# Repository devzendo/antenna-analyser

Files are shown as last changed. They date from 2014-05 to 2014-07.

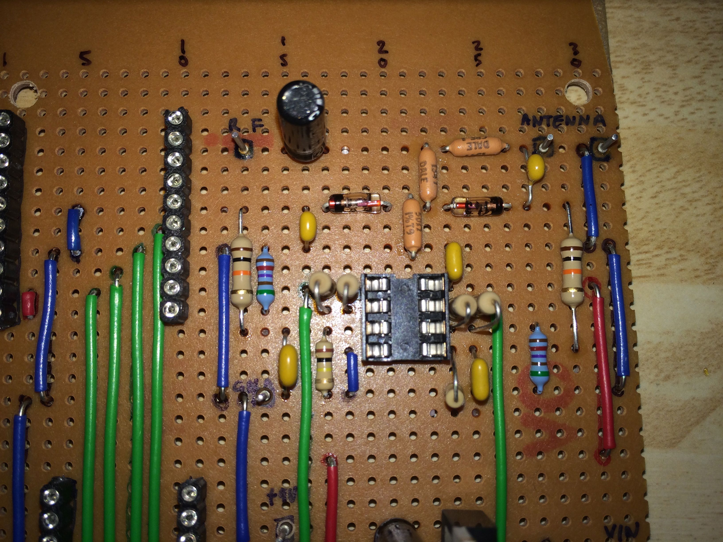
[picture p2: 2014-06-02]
IMG_2970.jpg

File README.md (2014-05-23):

antenna-analyser
================

Code, documents and details of one way to construct Beric Dunn K6BEZ' inexpensive antenna analyser.

Details of Beric's project's several variations, and schematics can be found at http://www.hamstack.com/project_antenna_analyzer.html

This repository, and the blog posts at http://mattgumbley.wordpress.com/category/amateur-radio/antenna-analyser/ hold
details of my construction attempts, board layouts, component costs, software, tests, and articles on VSWR (my
attempts to learn more about it by writing about it) and RF circuit design.

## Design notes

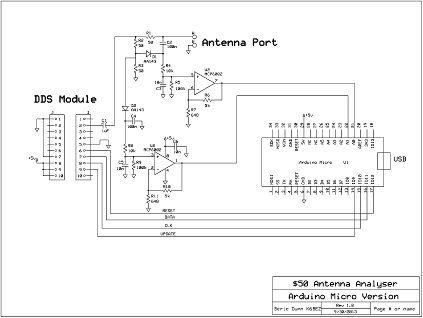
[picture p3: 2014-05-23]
BericSchematicSmall.png

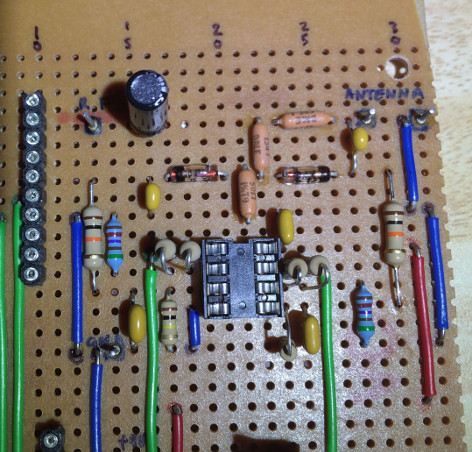
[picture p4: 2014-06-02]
PhotoBridgeDetail.jpg

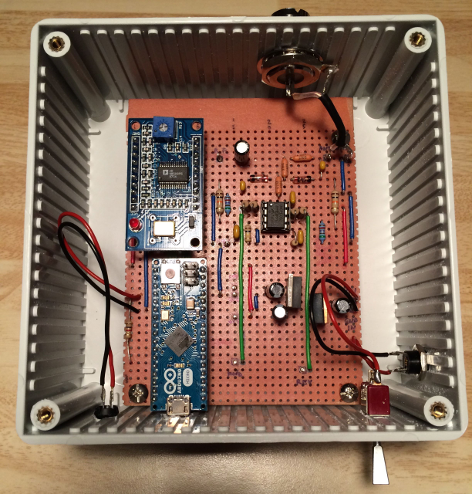
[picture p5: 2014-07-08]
PhotoEnclosureOpen.png

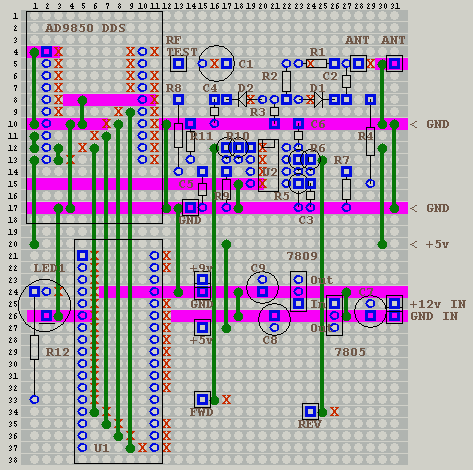
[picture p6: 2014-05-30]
GroundContinuity.png

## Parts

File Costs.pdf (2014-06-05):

## Sheet1

## Page 1

| | | Farnell | RS | Chosen
Component | Value | Num | Code | Cost | Code | Cost | Cost | Total Note
U1 | Arduino Micro | 1 | | | 771-7667 | £15.74 | £15.74 | £15.74 With headers
DDS | DDS Module | 1 | | | | | £7.99 | £7.99 | AD9850 DDS Signal 0-40MHz from 'heavends' on eBay (UK merchant)
U2 | MCP6002 | 1 | | | 403-036 | £0.24 | £0.24 | £0.24 MCP6002-I/P Dual Op-Amp 1MHz CMOS R-R 3, 5V 8-Pin PDIP
U3 | LM7805CT | 1 | | | 671-0309 | £0.49 | £0.49 | £0.49
U4 | L7809CV | 1 | 1087089 | £0.42 | | | £0.42 | £0.42
D1,2 | AA143 | 2 | | | | | £0.60 | £1.20 Germanium RF diode from 'slamme58' on eBay (from Denmark; bought 10pk)
LED1 | Green, med size | 1 | | | 646-6658 | £0.05 | £0.05 | £0.05 For the 'Scan in Progress' LED. Arduino Micro has a built-in one, but want case-mounted
C1 | 1uF elec | 1 | | | 3654199 | £0.07 | £0.07 | £0.07
C2,4 | 100nF ceramic | 2 | | | 5381203 | £0.16 | £0.16 | £0.32 =0.1uF
C3,5,6 | 10nF ceramic | 3 | 1650710 | £0.18 | | | £0.18 | £0.54 =0.01uf, 10000pf
C7,8,9 | 10uF elec | 3 | 2346601 | £0.07 | | | £0.07 | £0.21 For the power supply
R1,2,3 | 50Ω | 3 | 2396015 | £0.37 | | | £0.37 | £1.11 Metal film 1% axial
R4,8,12 | 10KΩ | 3 | | | 132-731 | £0.03 | £0.03 | £0.08 Carbon film 0.5W
R5,9 | 100KΩ | 2 | | | 7078388 | £0.02 | £0.02 | £0.04 Carbon 0.5W, 5%
R6,10 | 5KΩ (2 x 10KΩ ea) | 4 | | | 132-731 | £0.03 | £0.03 | £0.10 Could not find cheap 5KΩ resistors so am using 2 x 10KΩ in parallel
R7,11 | 649Ω | 2 | 1563247 | £0.37 | | | £0.37 | £0.74 Circuit required 648Ω but could not find, so chose 649Ω, 0.25W, 0.5%, 50PPM
ANT | 50Ω | 1 | 1169707 | £1.68 | | | £1.68 | £1.68 UHF bulkhead RF coaxial socket, takes a PL-259
PWRSOCK | Socket | 1 | 1243247 | £1.07 | | | £1.07 | £1.07 Power socket
PWRPLUG | Plug | 1 | 1568397 | £1.18 | | | £1.18 | £1.18 Power plug, 4A, 12V
CASE | | 1 | 1877411 | £5.56 | | | £5.56 | £5.56 120x120x59mm, grey ABS
DIP8 | 8-pin DIP Socket | 1 | | | 813115 | £0.35 | £0.35 | £0.35
PINSTRIP | 32 way pin strip | 2 | | | 2677416 | £0.75 | £0.00 | £0.00 For Arduino and DDS
BOARD | Veroboard | 1 | 1536938 | £6.73 | | | £6.73 | £6.73 | Need '38 strips x 31 holes, 96mm x 81mm, 2.54mm hole spacing stripboard.
| | | | | | | | | This is 121.92mm x 101.6mm, 41 tracks x 44 holes
| | | | | | | Grand Total
| | | | | | | | £45.93

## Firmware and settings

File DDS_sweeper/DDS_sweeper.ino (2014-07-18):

/***************************************************************************\
*  Name    : DDS_Sweeper.BAS                                                *
*  Author  : Beric Dunn (K6BEZ)                                             *
*  Notice  : Copyright (c) 2013  CC-BY-SA                                   *
*          : Creative Commons Attribution-ShareAlike 3.0 Unported License   *
*  Date    : 18 Jul 2014                                                    *
*  Version : 1.1/M0CUV                                                      *
*  Notes   : Written using for the Arduino Micro                            *
*          :   Pins:                                                        *
*          :    A0 - Reverse Detector Analog in                             *
*          :    A1 - Forward Detector Analog in                             *
\***************************************************************************/

// Define Pins used to control AD9850 DDS
const int FQ_UD=10;
const int SDAT=11;
const int SCLK=9;
const int RESET=12;

// Pins for Fwd/Rev detectors
const int REV_ANALOG_PIN = A0;
const int FWD_ANALOG_PIN = A1;

// "ON/Scan in progress" LED on M0CUV board
const int LED=8;
// Inbuilt LED on Arduino Micro, fades waiting for input
const int INTLED=13;

int brightness = 0;    // how bright the LED is
int fadeAmount = 1;    // how many points to fade the LED by
int countdown = 1024;   // only change brightness when this wraps round zero, so no delay needed

double Fstart_MHz = 1;  // Start Frequency for sweep
double Fstop_MHz = 10;  // Stop Frequency for sweep
double current_freq_MHz; // Temp variable used during sweep
long serial_input_number; // Used to build number from serial stream
int num_steps = 100; // Number of steps to use in the sweep
char incoming_char; // Character read from serial stream
int settle_delay = 10; // How long to wait in ms after setting the frequency before reading the voltages.
int oscilloscope_pin = FWD_ANALOG_PIN; // Read the forward detector, unless overridden.

// the setup routine runs once when you press reset:
void setup() {
  // Configiure DDS control pins for digital output
  pinMode(FQ_UD,OUTPUT);
  pinMode(SCLK,OUTPUT);
  pinMode(SDAT,OUTPUT);
  pinMode(RESET,OUTPUT);
  
  // Configure LED pin for digital output
  pinMode(LED,OUTPUT);
  pinMode(INTLED,OUTPUT);
  
  // The unit is now "ON"
  LED_on();

  // Set up analog inputs, internal reference voltage
  pinMode(REV_ANALOG_PIN,INPUT);
  pinMode(FWD_ANALOG_PIN,INPUT);
  analogReference(INTERNAL);
  
  // initialize serial communication at 57600 baud
  Serial.begin(57600);

  // Reset the DDS
  ResetDDS();
  
  // Initialise the incoming serial number to zero
  serial_input_number=0;
}

// the loop routine runs over and over again forever:
void loop() {
  //Check for character
  if(Serial.available()>0){
    incoming_char = Serial.read();
    switch(incoming_char){
    case '0':
    case '1':
    case '2':
    case '3':
    case '4':
    case '5':
    case '6':
    case '7':
    case '8':
    case '9':
      serial_input_number=serial_input_number*10+(incoming_char-'0');
      break;
    case 'A':
      //Turn frequency into FStart
      Fstart_MHz = ((double)serial_input_number)/1000000;
      serial_input_number=0;
      break;
    case 'B':
      //Turn frequency into FStop
      Fstop_MHz = ((double)serial_input_number)/1000000;
      serial_input_number=0;
      break;
    case 'C':
      //Turn frequency into FStart and set DDS output to single frequency
      Fstart_MHz = ((double)serial_input_number)/1000000;
      SetDDSFreq(Fstart_MHz*1000000);
      serial_input_number=0;    
      break;
    case 'D':
      // Set the settle delay in the sweep
      settle_delay = serial_input_number;
      serial_input_number=0;
      break;
    case 'E':
      // Oscilloscope reads rEverse detector
      oscilloscope_pin = REV_ANALOG_PIN;
      break;
    case 'F':
      // Oscilloscope reads Forward detector
      oscilloscope_pin = FWD_ANALOG_PIN;
      break;
    case 'N':
      // Set number of steps in the sweep
      num_steps = serial_input_number;
      serial_input_number=0;
      break;
    case 'O':
    case 'o':
      Perform_oscilloscope();
      break;
    case 'Q':
    case 'q':
      Serial.println("K6BEZ Antenna Analyser, modifications by M0CUV");
      Serial.println("Commands: ABCDEFNOQSRV?");
      break;
    case 'S':    
    case 's':    
      Perform_sweep();
      break;
    case 'R':    
    case 'r':    
      ResetDDS();
      Serial.println("Reset");
      break;
    case 'V':
    case 'v':
      Read_voltages();
      break;
    case '?':
      // Report current configuration to PC    
      Serial.print("Start Freq:");
      Serial.println(Fstart_MHz*1000000);
      Serial.print("Stop Freq:");
      Serial.println(Fstop_MHz*1000000);
      Serial.print("Num Steps:");
      Serial.println(num_steps);
      break;
    }
    Serial.flush();     
  } 
  
  fade();
}

void fade() {
  countdown --;

  if (countdown == 0) {
    countdown = 1024;

    analogWrite(INTLED, brightness);    
    // change the brightness for next time through the loop:
    brightness = brightness + fadeAmount;

    // reverse the direction of the fading at the ends of the fade: 
    if (brightness == 0 || brightness == 255) {
      fadeAmount = -fadeAmount ; 
    }     
  }  
}

void LED_on() {
  digitalWrite(LED, HIGH);   // turn the LED on (HIGH is the voltage level)
}

void LED_off() {
  digitalWrite(LED, LOW);    // turn the LED off by making the voltage LOW
}

// An oscilloscope showed some spikes in the detector voltages at regular
// intervals, so I thought I could filter these out by taking the mode of
// several measurements. However, the oscilloscope plot of this firmware
// and the C driver showed that the mode is typically 0, and the smoothed
// values are sinusoidal. So, just average it. 80 measurements is around
// two cycles.
double analog_read_value(int pin) {
double total = 0.0;
double reading;
int i;
  for (i=0; i< 80; i++) {
    reading = analogRead(pin);
    total += reading * reading;
  }
  return total / 80.0;
}

void Perform_sweep(){
  double FWD=0;
  double REV=0;
  double VSWR;
  double Fstep_MHz = (Fstop_MHz-Fstart_MHz)/num_steps;
  int LED_voltage = HIGH;
  int last_flip = 0;

  // Set the start frequency - sometimes, this doesn't seem to work.
  // Need a way of obtaining feedback that it has worked...
  SetDDSFreq(Fstart_MHz*1000000);
  SetDDSFreq(Fstart_MHz*1000000);
  SetDDSFreq(Fstart_MHz*1000000);
  SetDDSFreq(Fstart_MHz*1000000);
  
  // Start loop 
  for(int i=0;i<=num_steps;i++){
    //digitalWrite(LED, LED_voltage);
    
    if(Serial.available()>0) {
      Serial.println("Stop");
      break;
    }
    // Calculate current frequency
    current_freq_MHz = Fstart_MHz + i*Fstep_MHz;
    
    // Set DDS to current frequency
    SetDDSFreq(current_freq_MHz*1000000);

    last_flip += settle_delay;
    if (last_flip > 100) {
      LED_voltage = LED_voltage == HIGH ? LOW : HIGH;
      last_flip = 0;
    }
    
    // Read the forawrd and reverse voltages
    REV = analog_read_value(REV_ANALOG_PIN);
    FWD = analog_read_value(FWD_ANALOG_PIN);

    if(REV >= FWD){
      // To avoid a divide by zero or negative VSWR then set to max 999
      VSWR = 999;
    } else {
      // Calculate VSWR
      VSWR = (FWD+REV)/(FWD-REV);
    }
    
    // Send current line back to PC over serial bus
    Serial.print(current_freq_MHz*1000000);
    Serial.print(",0,");
    Serial.print(VSWR*1000.0);
    Serial.print(",");
    Serial.print(FWD);
    Serial.print(",");
    Serial.println(REV);
  }
  // Send "End" to PC to indicate end of sweep
  Serial.println("End");
  Serial.flush();    

  LED_on();
  ResetDDS();
}

void Perform_oscilloscope() {
const int buffer_size = 256;
int fwd_values[buffer_size];
int i;

  if (Fstart_MHz != 0) {
    // Set DDS to A frequency
    SetDDSFreq(Fstart_MHz*1000000);
  }

  for (i = 0; i < buffer_size; i++) {
    fwd_values[i] = (int)analogRead(oscilloscope_pin);
  }
  for (i = 0; i < buffer_size; i++) {
    Serial.print(i);
    Serial.print(" ");
    Serial.println(fwd_values[i]);
  }
  // Send "End" to PC to indicate end of scope
  Serial.println("End");
  Serial.flush();    

  LED_on();
  ResetDDS();
}

void Read_voltages() {
  double FWD=0;
  double REV=0;
  double VSWR;
  // Read the forawrd and reverse voltages
  REV = analog_read_value(REV_ANALOG_PIN);
  FWD = analog_read_value(FWD_ANALOG_PIN);
  if (REV >= FWD) {
    // To avoid a divide by zero or negative VSWR then set to max 999
    VSWR = 999;
  } else {
    // Calculate VSWR
    VSWR = (FWD+REV)/(FWD-REV);
  }
  Serial.print("VSWR: ");
  Serial.print(int(VSWR*1000));
  Serial.print(", Forward: ");
  Serial.print(FWD);
  Serial.print(", Reverse: ");
  Serial.println(REV);
}

void ResetDDS() {
  digitalWrite(RESET,HIGH);
  // tRS = 5 clock cycle reset width:
  // (5/125,000,000) secs in milliseconds = 4 ms
  delay(4);
  digitalWrite(RESET,LOW);
}

void SetDDSFreq(double Freq_Hz){
  // Calculate the DDS word - from AD9850 Datasheet
  int32_t f = Freq_Hz * 4294967295/125000000;
  // Send one byte at a time
  for (int b=0;b<4;b++,f>>=8){
    send_byte(f & 0xFF);
  }
  // 5th byte needs to be zeros
  send_byte(0);
  // Strobe the Update pin to tell DDS to use values
  digitalWrite(FQ_UD,HIGH);
  // 7.0ns
  delay(1);
  digitalWrite(FQ_UD,LOW);

  // Wait a little for settling
  delay(settle_delay);
}

void send_byte(byte data_to_send){
  // Bit bang the byte over the SPI bus
  for (int i=0; i<8; i++,data_to_send>>=1){
    // Set Data bit on output pin
    digitalWrite(SDAT,data_to_send & 0x01);
    // Strobe the clock pin
    digitalWrite(SCLK,HIGH);
    digitalWrite(SCLK,LOW);
  }
}

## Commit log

2014-05-23 Added initial spreadsheet detailing May 2014 UK costs of components
    [Costs.ods]
2014-05-23 Add Beric's Schematic
2014-05-23 Add Beric's Schematic (half size thumbnail)
2014-05-27 Add the VeroDes .vbd design file, and bitmaps of the component and track layouts produced by it
2014-05-27 Got the voltage regulator wrong; should have been a 7809
2014-05-27 Updated costs with LED, resistors for the R10/R6 parallel network
    [Costs.ods]
2014-05-27 Added pinout of the AD9850, from http://arduino.alhin.de/index.php?n=7
2014-05-27 Add the pinout for the AD9850 board, from http://arduino.alhin.de/index.php?n=7
2014-05-27 The original version of Beric Dunn K6BEZ' Arduino Micro firmware from http://www.hamstack.com/hs_projects/antenna_analyzer_mcu.zip
2014-05-28 Added and corrected some track breaks with the aid of VeroDes track continuity view, moved a couple of passives around, removed misleading rail annotation
2014-05-30 Add another ground pin, since the one in the PSU area is fine for testing PSU voltage, but could get shorted against the +9v. Add continuity check diagrams.
    [VeroAttempt1.brd, VeroAttempt1.sch]
2014-05-30 Revert "Add another ground pin, since the one in the PSU area is fine for testing PSU voltage, but could get shorted against the +9v. Add continuity check diagrams."
    This reverts commit e45e07cb6468e0b70fc929eb6774b6a3d1372fa9.
    [VeroAttempt1.brd, VeroAttempt1.sch]
2014-06-02 Moved Beric's source to its own directory as required by Arduino 1.0.5
2014-06-02 Turn the "scan in progress" LED on around a scan, and use the internal LED to pulse to show that the board is running.
2014-06-02 Pulse the internal LED slower, to distinguish from the boot loader/POST. (Whatever's built-in, and pulses at the rate this used to, before the loop() is called).
2014-06-05 Add pictures of the finished board, with and without Arduino and DDS boards. Also a picture of the sine output from the oscilloscope.
2014-06-05 Strike out the pin strips from the costs, as I got the wrong type that has sockets that are slightly too small to fit the Arduino and DDS module pins.
    [Costs.ods]
2014-07-03 Bug fix: Correct the C command's setting of the immediate frequency. Allow the settle delay to be configured with the D command, default is 10ms. Extract reset DDS code to its own function. Reset the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
    [DDS_sweeper.ino]
2014-07-03 Use the LED as a power (solid) and scan (flashing) indicator
2014-07-06 Add small delay into the reset code, as per AD9850 data sheet; move settle_delay delay into the set frequency routine. Add a basic 'oscilloscope mode' to show the detector voltages, as I suspect nois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
    [DDS_sweeper.ino]
2014-07-06 Extract analogRead to its own function so I can return the mode of a few values; knock out fade, as the noise I'm seeing seems to be exacerbated by it.
    [DDS_sweeper.ino]
2014-07-08 Add ATmega16U4/32U4 data sheet and summary - the Arduino Micro
2014-07-08 Investigating noise: remove fading / flashing LED effects, first cut of an analog read using the mode of several measurements, Set the DDS frequency several times as it doesn't always set reliably fi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
    [DDS_sweeper.ino]
2014-07-18 Use constants for the forward and reverse detector analogue input pins; allow the pin measured by the oscilloscope mode to be specified with E (reverse) and F (forward) commands.
    [DDS_sweeper.ino]
